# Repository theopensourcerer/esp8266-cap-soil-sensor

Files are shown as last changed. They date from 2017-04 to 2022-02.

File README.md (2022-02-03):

# ESP8266 Capacitive Soil Moisture Sensor
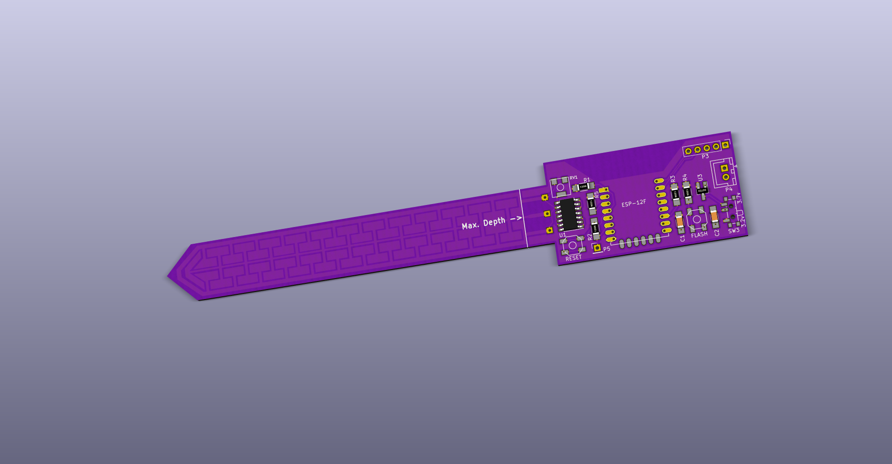
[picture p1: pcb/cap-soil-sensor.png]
Image of PCB

## Table of Contents
* [Summary](#summary)
* [Hardware](#hardware)
* [Case](#case)
* [Code](#code)
* [Licenses](#licenses)

## Summary
This is a personal project to build a Capacitive Soil Moisture Sensor for my hobby of growing chillies.

The project consists of three parts: the hardware (PCB and Sensor(s) etc.(, the case to hold the sensor, and the software.

I wanted to design and build my own sensors with built in WiFi so they could operate "standalone" in my tunnel. I wanted them to run from a decent capacity battery such as an 18650 Li-ion and to be able to report back information at timely intervals to my home server and database. Ultimately I want to use this information to be able to automate the watering of my plants.

The Internet is a wonderful thing. I have spent many dark and long evenings through the 2016/17 winter, learning, reading and searching for information on Capacitive moisture sensors. There are numerous resources (and individual people behind each of them) I would like to thank for taking the time to design, document and discuss the various mechanisms for capacitive moisture measurement. Hopefully my own small contributions may help others in the future.

Why use capacitive sensors? 

* The cheap and traditional moisture sensor uses a resistive technique. That is, to put it simply, the probe usually consists of two electrically conductive "prongs" which are inserted into the soil with a known gap between them. As the moisture increases, the electrical resistance decreases. This technique works but is not ideal mostly due to electrolysis [1]. Essentially the probes deteriorate rapidly due to this phenomenom and hence the measurements also change and the probes need to be replaced quite frequently

* The resitive appraoch requires significantly more power (electric current) to operate than the capacitive technique, so battery life would be constrained

* The fundamental principle of the capacitive sensor is that you measure the time it takes for your capacitor (the probe) to charge. This charging period changes proportionately to the moisture level of the soil. It means there is no direct electrical contact between the soil and the probe (it is insulated) therefore should last a great deal longer

* It is harder to do; hence far more interesting to design and produce ;-)

Below is my list, in no particular order, of the online resources I found to be most helpful during my research (there were and are others; Google is your friend):

http://pcb.daince.net/doku.php?id=sensor_soil_2
http://zerocharactersleft.blogspot.co.uk/2011/11/pcb-as-capacitive-soil-moisture-sensor.html

https://www.dfrobot.com/wiki/index.php/Capacitive_Soil_Moisture_Sensor_SKU:SEN0193 (Bought one of these to test. It works)
https://github.com/Miceuz/i2c-moisture-sensor
and
https://wemakethings.net/chirp/ (Bought one of these - this works too)

http://www.instructables.com/id/Comparison-of-Capacitive-Soil-Probes/
and then
https://github.com/acolomitchi/cap-soil-moisture-v2 (I have used this probe design. Thanks acolomitchi)

Then I came across these few resources (thank you Google Translate)
* https://www.mikrocontroller.net/topic/335407

Which led me here:
* http://shop.thomasheldt.de/product_info.php?info=p90_giess-o-mat-sensor-kit.html (Bought a couple of these and they work)

Which then led me to:
* https://github.com/Zentris/erdfeuchtemessung

and
* https://github.com/lh84/moisture_sensor_esp12

I have also been following along with this project:
* https://luckyresistor.me/2017/02/08/how-to-design-a-cheap-plant-watering-sensor-part-1/
I really like the way this project has been analysed, designed and documented - much more so than mine which is a "try-something-and-see-if-it-works" approach.

These resources above gave me confidence that a custom design was possible so I set to work basing the Schematic and PCB on the work of the people above. The use of a Schmitt Trigger Inverter to "square" up the oscillations of the sensor probe means it can be read by pretty much any GPIO as long as the MCU is fast enough. The ESP8266 has some limitations in this regard so I considered using a half-wave rectifier to convert this to a simple analogue voltage but the work of Zentris and Lars(lh84) convinced me that the ESP8266 was capable of reading the frequency directly if it can be kept below about 150Khz.

This is _all_ still very much a work in progress. I have built a prototype board and have had it running on my desk but the results leave me rather confused :-(

## Hardware
The Schematic and PCB are designed in KiCAD. A version of this board has been fabricated but it is not the final version. Probably the most interesting part is the layout of the probe footprint itself. This came from acolomitchi as mentioned above. (I have modified the layout somewhat so it is more suited to an integrated PCB - I also made it a little longer as my target was for quite large pots).

## Case
The case is designed in OpenSCAD and is suitable for printing on a 3D Printer. The basic idea is that the PCB slides into the case. The PCB has about 1.5mm of empty space down each side of the board which should be enough to slot in place. The probe end of the PCB fits through the slot in the bottom of the case. There should be enough height to support the power connector (not tested) and the other half of the case holds an 18650 battery in a plastic holder. The "lid" screws on and has protrusions which should prevent the probe PCB and the battery from moving about too much. I plan to use something like silicon bathrooom sealant around the probe slot to prevent any moisture ingressing into the case. Please feel free to use and improve - within the terms of the license of course.

## Code
The software for the ESP8266 is in this directory. It should be fairly simple C code. The config.h file contains user-defined parameters. The ESP8266 code works like this: On power up the ESP attempts to connect to the WiFi network. If successful it then attempts to read the frequency of the capacitive sensor probe. If the Sensor probe is read successfully the data is formatted as a JSON object and sent to the MQTT broker. The ESP8266 also sends information about its supply voltage and the time it took to run this code loop. Finally the code puts the ESP into "Deep Sleep" for a preconfigured period.

## Licenses
* The software is GPL (http://www.gnu.org/licenses/) 
* The OpenSCAD case design, and the Schematic and PCB are Creative Commons Attribution-NonCommercial-ShareAlike 4.0 International Public License (https://creativecommons.org/licenses/by-nc-sa/4.0/)

[1] https://en.wikipedia.org/wiki/Electrolysis

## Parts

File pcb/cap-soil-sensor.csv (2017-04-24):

Reference | Value | Footprint | Datasheet | BOM
C1 | 10uF | Capacitors_SMD:C_1206_HandSoldering
C2 | 1uF | Capacitors_SMD:C_1206_HandSoldering
R2 | 100 | Resistors_SMD:R_1206_HandSoldering
U2 | ESP-12F | ESP8266:ESP-12E
U3 | MCP1700T | TO_SOT_Packages_SMD:SOT-23_Handsoldering |  | IC MICROCHIP MCP1700T-vv02E/TT
P4 | PWR | Connectors_JST:JST_XH_B02B-XH-A_02x2.50mm_Straight
P3 | SERIAL | Pin_Headers:Pin_Header_Straight_1x05_Pitch2.54mm
R1 | 10k | Resistors_SMD:R_1206_HandSoldering
R3 | 10k | Resistors_SMD:R_1206_HandSoldering
R4 | 10k | Resistors_SMD:R_1206_HandSoldering
R5 | 10k | Resistors_SMD:R_1206_HandSoldering
RV1 | POT-BOURNS-3364W | manuf:BOURNS-3364-W
SW3 | Switch_SPDT_x2 | switches:SW_SPDT_PCM12
P5 | INSPECTION | Pin_Headers:Pin_Header_Straight_1x01_Pitch2.54mm
CS1 | CS | cap-sensor:cap_sensor_probe
SW1 | RESET | switches:SKQGAFE010_Switch
SW2 | FLASH | switches:SKQGAFE010_Switch
U1 | 74LS14 | KiCad/Housings_SOIC.pretty:SOIC-14_3.9x8.7mm_Pitch1.27mm

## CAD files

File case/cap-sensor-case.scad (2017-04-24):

/**
 * Case for Capacitive Soil Sensors
 * 
 * License: Creative Commons Attribution-ShareAlike 4.0 International
 * Copyright 2017 Alan Lord
**/
$fn = 50;

l = 80;
w = 35;
h = 43;

prbw = 17;
prbd = 2;

wall = 2;

nutSize = 6;
nutHeight = 3;
nutThread = 3.2;
boltLength = 8;
fix=8;

pcbw = 29.5;
pcbh = 52.5;
pcbpad = 6.5;

pcbwctrs = 20.320;
pcbdctrs = 51.435;

sloth=((w-pcbw)/2)+1.5;

slotDepthFromTop = 15;

// Display the box
box();

// Display the lid
%lid();

module box() {
    %difference() { // The % makes the external wall transparent ot invisibble
        roundedCube(h+wall*2,w+wall*2,l+wall,nutThread);
        translate([wall,wall,wall]) {
            roundedCube(h,w,l,nutThread);
        }
        translate([slotDepthFromTop,((w+wall*2)-prbw)/2,0]) {
            cube([prbd,prbw,wall*2]);
        }
    }
    translate([slotDepthFromTop-wall,wall,wall]) {
        pcbSlot(pcbh);
    }
    translate([slotDepthFromTop-wall,w+wall-sloth,wall]) {
        pcbSlot(pcbh);
    }
    translate([slotDepthFromTop+wall*3,wall,wall]) {
        cube([1,w,l-wall*2]);
    }
    fixing();
    translate([0,(w+wall*2)-fix,0]) {
        fixing();
    }
    translate([(h+wall*2)-fix,(w+wall*2)-fix,0]) {
        fixing();
    }
    translate([(h+wall*2)-fix,0,0]) {
        fixing();
    }
    
    x=(h-22+wall);
    y=((w+wall*2)-21)/2;
    translate([x,y,wall]) {
        battery();
    }
}


module lid() {
    xtrns = nutHeight+wall+8.5;
    difference(){
        translate([0,0,l+wall]) {
            roundedCube(h+wall*2,w+wall*2,wall,nutThread);
        }
        translate([fix/2,fix/2,l+wall]) {
            cylinder(d=nutThread,h=wall);
        }
        translate([(h+wall*2)-fix/2,fix/2,l+wall]) {
            cylinder(d=nutThread,h=wall);
        }
        translate([(h+wall*2)-fix/2,(w+wall*2)-fix/2,l+wall]) {
            cylinder(d=nutThread,h=wall);
        }
        translate([fix/2,(w+wall*2)-fix/2,l+wall]) {
            cylinder(d=nutThread,h=wall);
        }
    }
    sloth=l-(pcbh+pcbpad)-1;
    translate([slotDepthFromTop-wall,((w+wall*2)-w)/2,l-sloth+wall]) {
        difference() {
            cube([wall*3,w,sloth]);
            translate([0,w/2,0]) {
                rotate([90,0,90]) cylinder(h=wall*3,d=5);
            }
        }
    }
    translate([h-10,(w+wall*2)/2,(l+wall)-3]) {
        cylinder(h=3,d=10);
    }

}

module bolt(width,height,thread,length,hull) {
    cylinder(d=width/(cos(180/6)), h=height, $fn=6);
    if(hull) {
        hull(){
            translate([0,0,height]) {
                cylinder(d=thread,h=length);
            }
            translate([thread,0,height]) {
                cylinder(d=thread,h=length);
            }
        }
    } else {
        translate([0,0,height]) {
            cylinder(d=thread,h=length);
        }
    }
}

module fixing() {
    difference() {
        translate([0,0,wall]){
            roundedCube(fix,fix,l,nutThread);
        }
        translate([fix/2,fix/2,l-(boltLength-wall)]) {
            cylinder(d=nutThread,h=boltLength);
        }
    }
}

module battery() {
    l=76;
    w=21;
    h=22;
    cube([h,w,l]);
}

module pcbSlot(l) {
    cube([wall,sloth,l+pcbpad]);
    translate([wall*2,0,0]) {
        cube([wall,sloth,l+pcbpad]);
    }
    translate([wall,0,0]) {
        cube([prbd,sloth,pcbpad]);
    }
}

module roundedCube(xdim,ydim,zdim,rdim) {
    hull() {
        translate([rdim,rdim,0]) cylinder(r=rdim,h=zdim);
        translate([xdim-rdim,rdim,0]) cylinder(r=rdim,h=zdim);
        translate([rdim,ydim-rdim,0]) cylinder(r=rdim,h=zdim);
        translate([xdim-rdim,ydim-rdim,0]) cylinder(r=rdim,h=zdim);
    }
}

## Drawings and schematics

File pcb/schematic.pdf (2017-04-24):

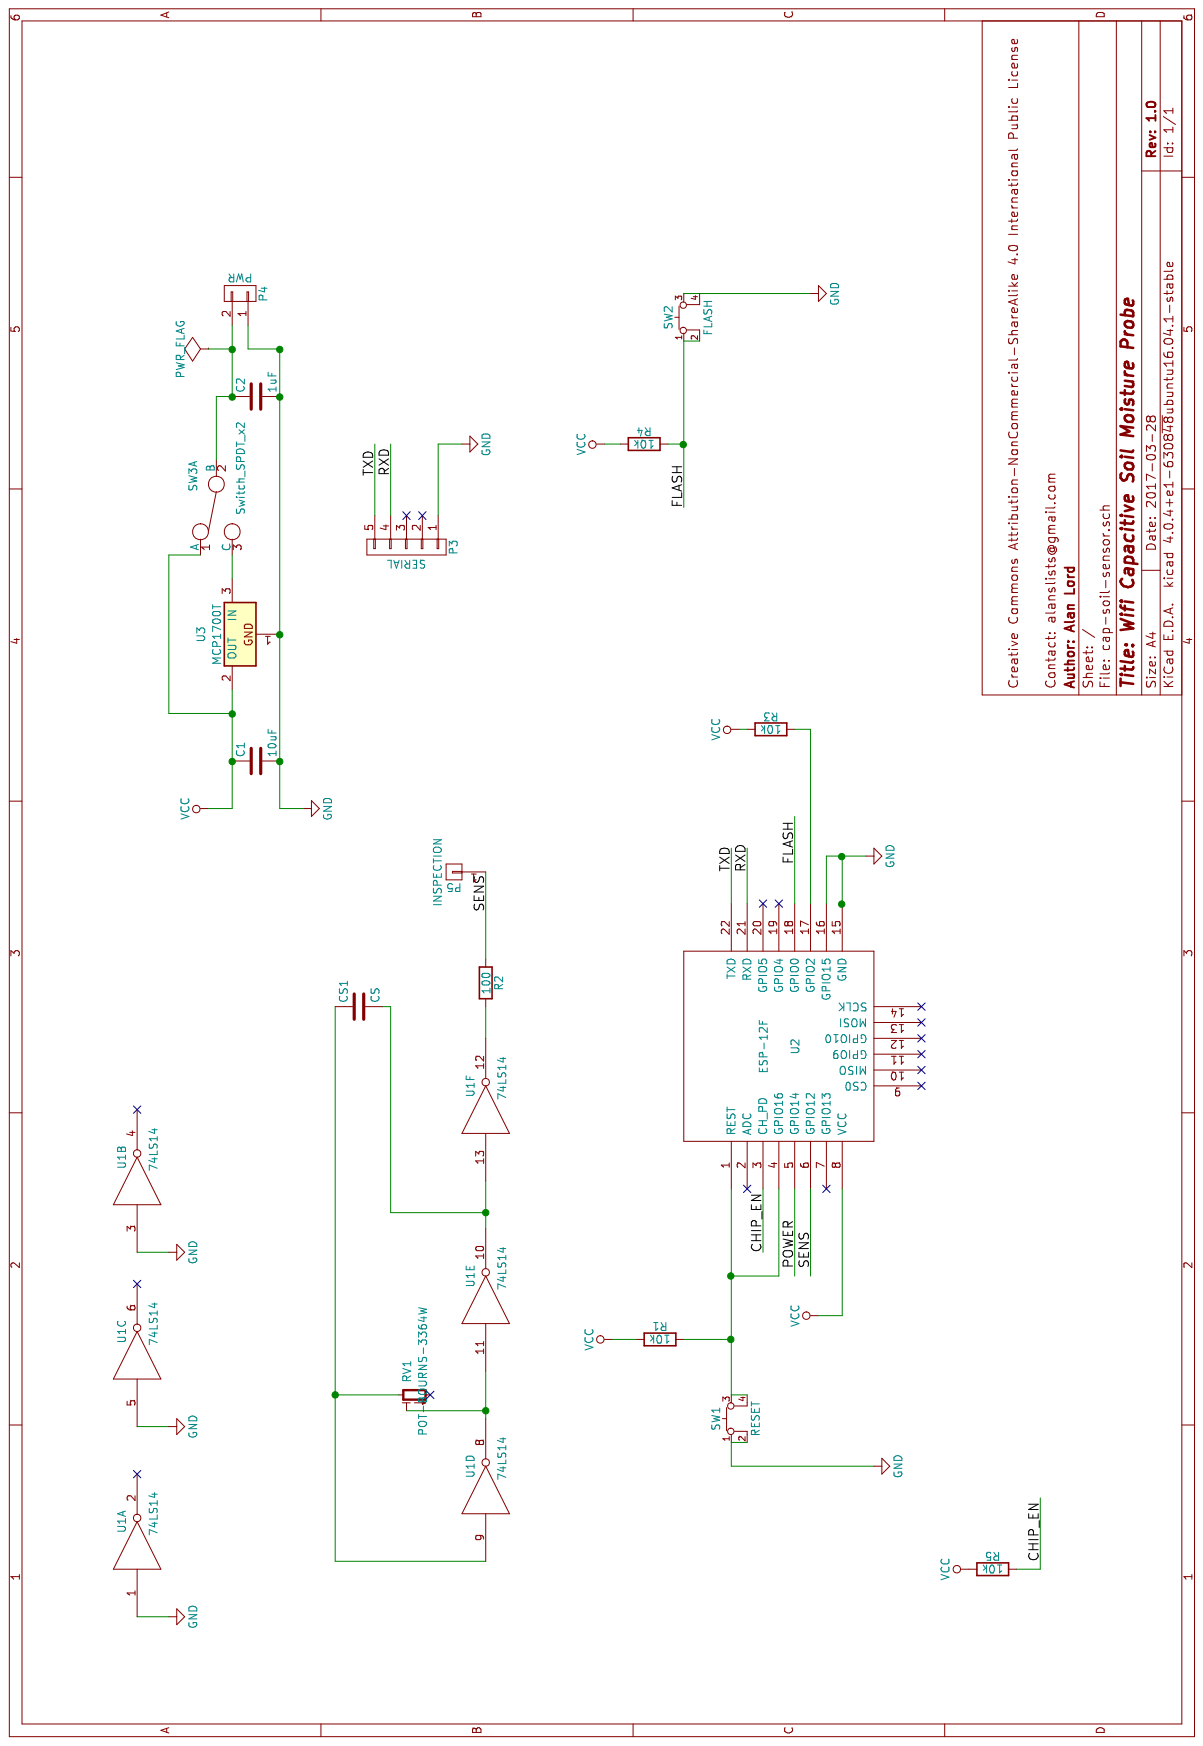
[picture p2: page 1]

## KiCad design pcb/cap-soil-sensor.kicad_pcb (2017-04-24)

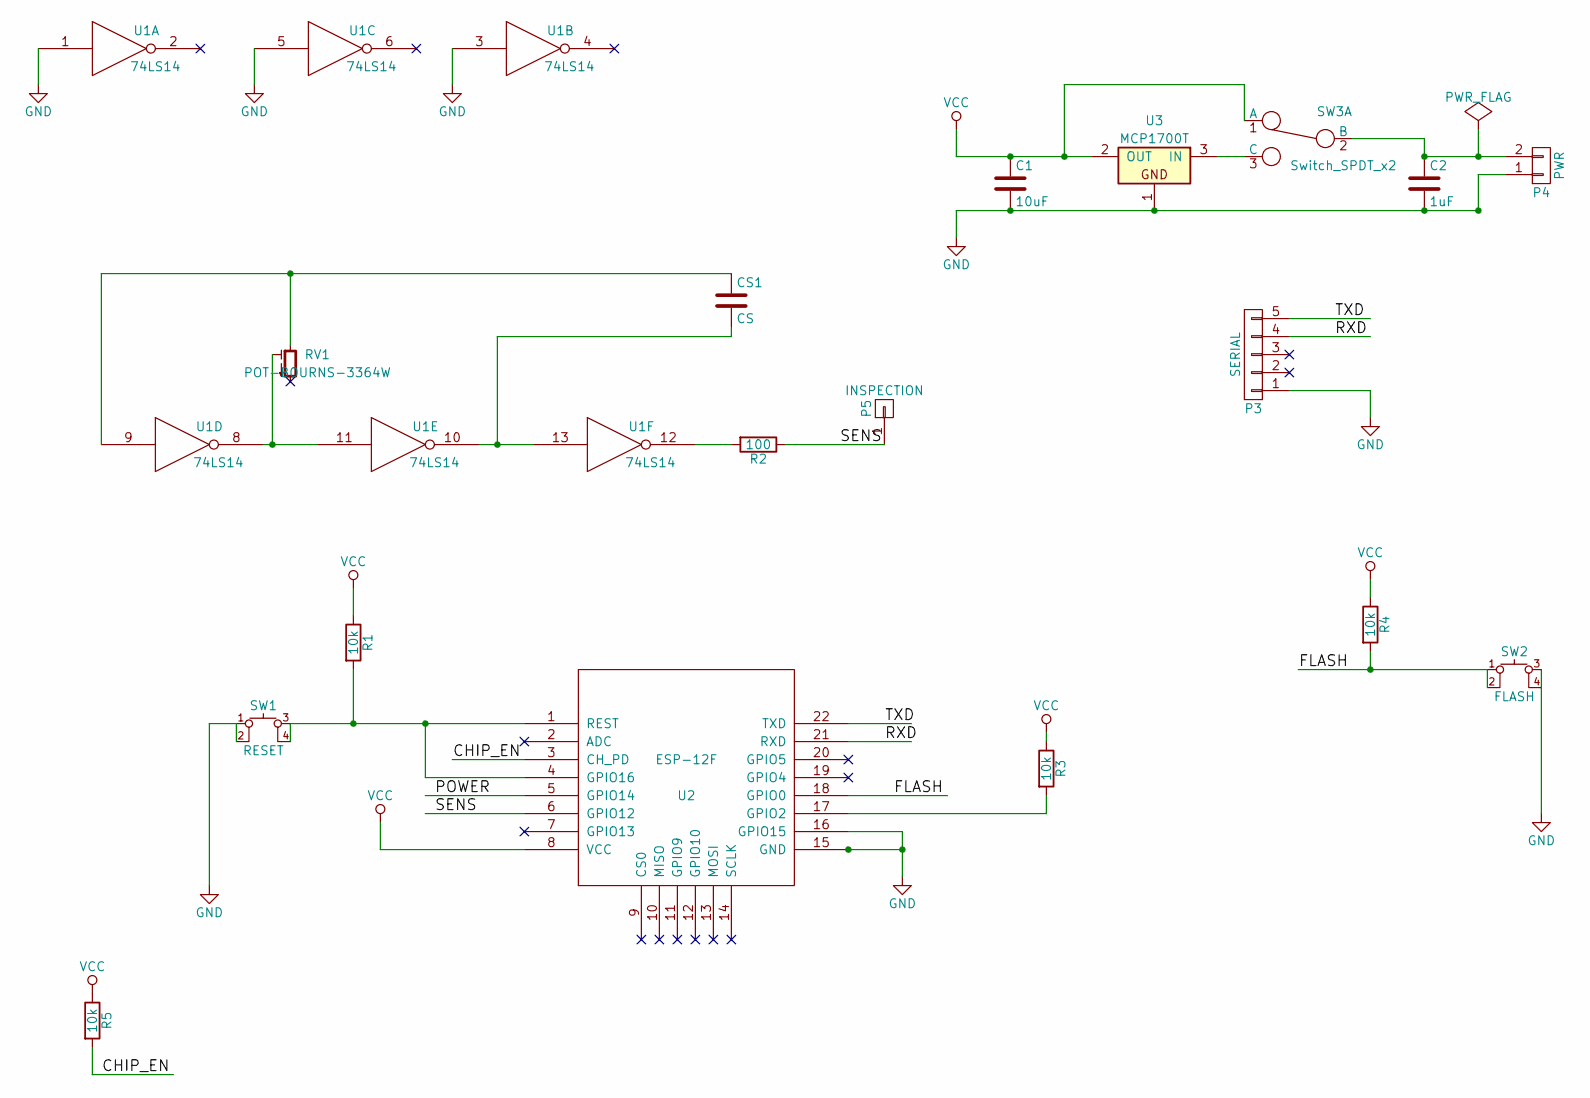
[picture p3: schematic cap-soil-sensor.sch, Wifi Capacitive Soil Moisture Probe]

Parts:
C1: 10uF; C_1206_HandSoldering
C2: 1uF; C_1206_HandSoldering
CS1: CS; cap_sensor_probe
P3: SERIAL; Pin_Header_Straight_1x05_Pitch2.54mm
P4: PWR; JST_XH_B02B-XH-A_02x2.50mm_Straight
P5: INSPECTION; Pin_Header_Straight_1x01_Pitch2.54mm
R1, R3, R4, R5: 10k; R_1206_HandSoldering
R2: 100; R_1206_HandSoldering
RV1: POT-BOURNS-3364W; BOURNS-3364-W
SW1: RESET; SKQGAFE010_Switch
SW2: FLASH; SKQGAFE010_Switch
SW3: Switch_SPDT_x2; SW_SPDT_PCM12
U1: 74LS14; SOIC-14_3.9x8.7mm_Pitch1.27mm
U2: ESP-12F; ESP-12E
U3: MCP1700T; SOT-23_Handsoldering

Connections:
/CHIP_EN: R5.2, U2.3 (CH_PD)
/FLASH: R4.2, SW2.1, SW2.2, U2.18 (GPIO0)
/RXD: P3.4, U2.21 (RXD)
/SENS: P5.1, R2.1, U2.6 (GPIO12)
/TXD: P3.5, U2.22 (TXD)
GND: C1.2, C2.2, P3.1, P4.1, SW1.1, SW1.2, SW2.3, U1.1, U1.3, U1.5, U1.7 (GND), U2.15 (GND), U2.16 (GPIO15), U3.1
unnamed: C2.1, P4.2, SW3.2 (B)
unnamed: CS1.1, RV1.3, U1.9
unnamed: CS1.2, U1.10, U1.13
unnamed: R1.2, SW1.3, SW1.4, U2.1 (REST), U2.4 (GPIO16)
unnamed: R2.2, U1.12
unnamed: R3.2, U2.17 (GPIO2)
unnamed: RV1.2, U1.8, U1.11
unnamed: SW3.3 (C), U3.3 (IN)
POWER: U1.14 (POWER), U2.5 (GPIO14)
VCC: C1.1, R1.1, R3.1, R4.1, R5.1, SW3.1 (A), U2.8 (VCC), U3.2 (OUT)

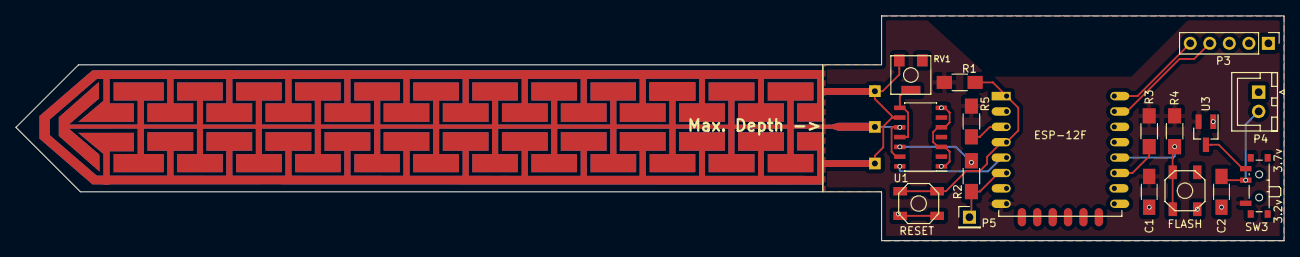
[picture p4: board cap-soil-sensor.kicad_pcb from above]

Board: 2 copper layers, 164.8 x 29.2 mm, 18 parts (0 on the bottom side), 16 nets.

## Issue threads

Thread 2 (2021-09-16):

ISR not in IRAM!

ChipStewart1, 2021-09-16:
I hope I'm not breaking protocol here, but I'm a bit of a noob.  After looking at some different projects, I thought this one looked like what I wanted, so I  had 20 boards printed up at JLC PCB and am trying to get them up and running.  I wasn't able to do it in PlatformIO, mostly because I couldn't get PubSubClient to work.  So I brought it over to Arduino IDE.  I got it to load (although I had to roll JSON back), but when I restart it, I get the following on the Serial Monitor:

...........
WiFi connected
IP address:
192.168.1.187
Attempting MQTT connection...Connected
ISR not in IRAM!

User exception (panic/abort/assert)
--------------- CUT HERE FOR EXCEPTION DECODER ---------------

Abort called

>>>stack>>>

ctx: cont
sp: 3ffffeb0 end: 3fffffc0 offset: 0000
3ffffeb0:  00000002 3ffffee2 3ffee748 4020350c
3ffffec0:  000000fe 00000000 00000000 00000000
3ffffed0:  00000000 00000000 00000000 00ff0000
3ffffee0:  5ffffe00 5ffffe00 401002a1 00000000
3ffffef0:  00000000 00000001 0000000c 4020512e
3fffff00:  401005a5 3ffee748 00000000 40205140
3fffff10:  00000000 00000002 0000000c 40205649
3fffff20:  3ffe8978 4b045454 c45a1c01 3ffee96c
3fffff30:  3fffff74 3ffee7b8 3fffff50 402056e8
3fffff40:  40203cf8 3ffe8976 3ffee82c 402012d4
3fffff50:  40203cf8 3ffe8976 3ffee82c 40203f64
3fffff60:  3fffdad0 00000009 3ffee82c 40204048
3fffff70:  00000000 3ffee748 3ffee82c 4020779d
3fffff80:  40207d50 3ffee748 3ffee82c 3ffee96c
3fffff90:  3fffdad0 00000000 3ffee958 40202255
3fffffa0:  feefeffe feefeffe feefeffe 40204c74
3fffffb0:  feefeffe feefeffe 3ffe863c 40100e61
<<<stack<<<

--------------- CUT HERE FOR EXCEPTION DECODER ---------------

 ets Jan  8 2013,rst cause:2, boot mode:(3,7)

load 0x4010f000, len 3460, room 16
tail 4
chksum 0xcc
load 0x3fff20b8, len 40, room 4
tail 4
chksum 0xc9
csum 0xc9
v00046480
~ld

...............................................

Any ideas how to solve this?  I'd like to start using these things!
Thanks,
Chip

theopensourcerer, 2021-09-17:
Gosh - I'm really sorry but I have not touched this project for about 5 years now. It really was, as I stated in the [Readme](https://github.com/theopensourcerer/esp8266-cap-soil-sensor/blob/master/README.md):

> "This is all still very much a work in progress. I have built a prototype board and have had it running on my desk but the results leave me rather confused :-("

As I recall there were some bugs in the PCB layout design too; it really was very much a prototype. i.e. things like the variable resistor should be replaced by a fixed one and most of the test points removed etc...

Having said all that it did "work" to a fashion on my desk in a pot but I never got any further than that, sorry.

ChipStewart1, 2021-09-22:
Thanks for your quick reply.  Looks like the only problem I can see now is due to the changes from json 5 to 6.  Unfortunately, I'm a beginner with PlatformIO and not familiar with json.  I think I was able to upgrade the first two json lines using the json upgrade guide, but can't figure out the others.  I'll post the errors below.  I'd greatly appreciate any help you could provide, and I'm sure others would benefit from a GitHub update.

BTW, I noticed you discussed PCB  water ingress and water proofing elsewhere online.  If you're interested, I'm comparing Liquid Tape, FlexSeal Clear, PlastiDip and perhaps silicone and/or urethane conformal coatings and can let you know the results.

Thanks
Chip

Oh, and let me know if you want me to send you some seeds from my Cajun Belle and Fish pepper plants.  The later is a very interesting African-American heirloom from the Philadelphia/Baltimore region with beautiful variegated leaves and fruit and Caribbean flavor and heat.

Errors:

src\main.cpp:140:11: error: StaticJsonBuffer is a class from ArduinoJson 5. Please see https://arduinojson.org/upgrade to learn how to upgrade your program to ArduinoJson version 6
.pio\libdeps\esp12e\PubSubClient\src\PubSubClient.cpp: In member function 'boolean PubSubClient::publish_P(const char*, const uint8_t*, unsigned int, boolean)':
.pio\libdeps\esp12e\PubSubClient\src\PubSubClient.cpp:523:16: warning: comparison of integer
expressions of different signedness: 'unsigned int' and 'int' [-Wsign-compare]
  523 |     return (rc == expectedLength);
      |             ~~~^~~~~~~~~~~~~~~~~
Compiling .pio\build\esp12e\lib80f\ESP8266WiFi\ESP8266WiFiSTA.cpp.o
Compiling .pio\build\esp12e\lib80f\ESP8266WiFi\ESP8266WiFiScan.cpp.o
Compiling .pio\build\esp12e\lib80f\ESP8266WiFi\WiFiClient.cpp.o
Compiling .pio\build\esp12e\lib80f\ESP8266WiFi\WiFiClientSecureBearSSL.cpp.o
src\main.cpp: In function 'void setup_wifi()':
src\main.cpp:82:31: warning: comparison of integer expressions of different signedness: 'long unsigned int' and 'long int' [-Wsign-compare]
   82 |     if (millis() - startMills > WIFI_TIMEOUT) {
      |         ~~~~~~~~~~~~~~~~~~~~~~^~~~~~~~~~~~~~
src\main.cpp: In function 'void publishJSON()':
src\main.cpp:140:21: error: expected primary-expression before '<' token
  140 |     StaticJsonBuffer<150> jsonBuffer;
      |                     ^
src\main.cpp:140:27: error: 'jsonBuffer' was not declared in this scope; did you mean 'JsonBuffer'?
  140 |     StaticJsonBuffer<150> jsonBuffer;
      |                           ^~~~~~~~~~
      |                           JsonBuffer
src\main.cpp:142:48: error: cannot bind non-const lvalue reference of type 'ArduinoJson::JsonArray&' {aka 'ArduinoJson6184_91::ArrayRef&'} to an rvalue of type 'ArduinoJson6184_91::ArrayRef'
  142 |     JsonArray& payload = root.createNestedArray("payload");
      |                          ~~~~~~~~~~~~~~~~~~~~~~^~~~~~~~~~~
src\main.cpp:143:50: error: cannot bind non-const lvalue reference of type 'ArduinoJson::JsonObject&' {aka 'ArduinoJson6184_91::ObjectRef&'} to an rvalue of type 'ArduinoJson6184_91::ObjectRef'
  143 |     JsonObject& data = payload.createNestedObject();
      |                        ~~~~~~~~~~~~~~~~~~~~~~~~~~^~
src\main.cpp:150:12: error: 'ArduinoJson::JsonObject' {aka 'class ArduinoJson6184_91::ObjectRef'} has no member named 'prettyPrintTo'
  150 |       root.prettyPrintTo(Serial);
      |            ^~~~~~~~~~~~~
src\main.cpp:154:10: error: 'ArduinoJson::JsonObject' {aka 'class ArduinoJson6184_91::ObjectRef'} has no member named 'printTo'
  154 |     root.printTo(buffer, sizeof(buffer));
      |          ^~~~~~~
src\main.cpp:155:5: warning: this 'if' clause does not guard... [-Wmisleading-indentation]
  155 |     if (client.publish(TOPIC, buffer));
      |     ^~
src\main.cpp:156:7: note: ...this statement, but the latter is misleadingly indented as if it were guarded by the 'if'
  156 |       if (DEBUG_PRINT) {
      |       ^~
*** [.pio\build\esp12e\src\main.cpp.o] Error 1

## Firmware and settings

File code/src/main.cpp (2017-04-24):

/*
                 GNU GENERAL PUBLIC LICENSE
                  Version 3, 29 June 2007
  This program is free software: you can redistribute it and/or modify
  it under the terms of the GNU General Public License as published by
  the Free Software Foundation, either version 3 of the License, or
  (at your option) any later version.
  This program is distributed in the hope that it will be useful,
  but WITHOUT ANY WARRANTY; without even the implied warranty of
  MERCHANTABILITY or FITNESS FOR A PARTICULAR PURPOSE.  See the
  GNU General Public License for more details.
  You should have received a copy of the GNU General Public License
  along with this program.  If not, see <http://www.gnu.org/licenses/>.
 - - - - - - - - - - - - - - - - - - - - - - - - - - - - - - - - - - - -

 Original code sources from:
  Erdfeuchtemessung mit ESP8266-01 / ESP8266-12(e)
  Measure soil moisture with ESP8266-01 / ESP8266-12(e)
  (2016)
  @Autors:
    - Ralf Wießner (aka Zentris)
  https://github.com/Zentris/erdfeuchtemessung
*/
#include "config.h"

#include <ESP8266WiFi.h>
#include <PubSubClient.h>
#include <ArduinoJson.h>

// Expose Espressif SDK functionality
extern "C" {
    #include "user_interface.h"
}

// Set up ESP8266 ADC for voltage read
ADC_MODE(ADC_VCC);
float vcc;

// Sensor average
unsigned long soilMoistAveraged;

volatile unsigned long counter = 0; // interrupt loop counter

// Timer placeholders
unsigned long startMills = 0;

// Function Prototypes
void readSensor();
void setup_wifi();
void reconnect();
void publishJSON();
void goingToSleep();
// End Prototypes

// Begin code
WiFiClient espClient;
PubSubClient client(espClient);

void setup() {
  startMills = millis();
  vcc = ESP.getVcc();
  Serial.begin(115200);

  digitalWrite(POWER_PIN, HIGH);  // switch sensor power on

  setup_wifi();
  client.setServer(MQTT_SERVER, 1883);
}

void setup_wifi() {
  // We start by connecting to a WiFi network
  if (DEBUG_PRINT) {
    Serial.println();
    Serial.print("Connecting to ");
    Serial.println(WIFI_SSID);
  }
  WiFi.begin(WIFI_SSID, WIFI_PASSWORD);

  while (WiFi.status() != WL_CONNECTED) {
    delay(500);
    Serial.print(".");
    if (millis() - startMills > WIFI_TIMEOUT) {
      if (DEBUG_PRINT) {
        Serial.println("Taken too long to connect to WiFi. Going to sleep");
      }
      goingToSleep();
    }
  }

  if (DEBUG_PRINT) {
    Serial.println("");
    Serial.println("WiFi connected");
    Serial.println("IP address: ");
    Serial.println(WiFi.localIP());
  }
}

void loop() {
  if (!client.connected()) {
    reconnect();
  }

  readSensor();

  if(soilMoistAveraged) {
    if (DEBUG_PRINT) {
      Serial.print("Read Sensor. Publish message: ");
    }
    publishJSON();
  }

  goingToSleep();
}

void reconnect() {
  // Loop until we're reconnected
  while (!client.connected()) {
    if (DEBUG_PRINT) {
      Serial.print("Attempting MQTT connection...");
    }
    // Attempt to connect
    if (client.connect("CapSensor")) {
      if (DEBUG_PRINT) {
        Serial.println("Connected");
      }
    } else {
      if (DEBUG_PRINT) {
        Serial.print("Failed to connect. State = ");
        Serial.print(client.state());
        Serial.println(" Retry in 2 seconds");
      }
      // Wait 2 seconds before retrying
      delay(2000);
    }
  }
}

void publishJSON() {
  if (client.connected()) {
    StaticJsonBuffer<150> jsonBuffer;
    JsonObject& root = jsonBuffer.createObject();
    JsonArray& payload = root.createNestedArray("payload");
    JsonObject& data = payload.createNestedObject();
    data["sensorid"] = SENSORNAME;
    data["moisture"] = soilMoistAveraged;
    data["vcc"] = vcc/1000;
    data["cycletime"] = millis() - startMills;
    if (DEBUG_PRINT) {
      Serial.print("Sending payload: ");
      root.prettyPrintTo(Serial);
    }

    char buffer[150];
    root.printTo(buffer, sizeof(buffer));
    if (client.publish(TOPIC, buffer));
      if (DEBUG_PRINT) {
        Serial.print("Published OK  --> ");
        Serial.println(millis() - startMills);
      }
    } else {
      if (DEBUG_PRINT) {
        Serial.print("Publish failed --> ");
        Serial.println(millis() - startMills);
      }
    }
}

/**
 * Simple median/average calculation
 * ------------------------------------
 * Getting array will be sorted and now get the average over the middle values
 */
unsigned long median(unsigned long *values, size_t arraySize) {
  unsigned long tmp = 0;     // set to 0, make the compiler happy :-)
  const size_t relVal = 2;   // +- 2 Werte + 1 für die Mittelwertberechnung

  for (size_t i=0; i < arraySize-2; i++) {
    for (size_t j=arraySize-1; j > i; j--) {
      if ( values[j] < values[j-1] ) {
        tmp = values[j];
        values[j] = values[j-1];
        values[j-1] = tmp;
      }
    }
  }

  if (DEBUG_PRINT) {
    for (size_t x=0; x<arraySize; x++) {
      Serial.print("Values: ");
      Serial.print(values[x]);
    }
  }

  tmp = 0;
  for (size_t i=arraySize/2-relVal; i<arraySize/2+relVal+1; tmp +=values[i++]) {}
  return tmp/(relVal*2+1) * 1000/MEASURING_TIME;
}

/**
 * Interrupt function: increment the counter
 */
void intfunc() {
  counter++;
}

void readSensor() {
  unsigned long dataArray[MEASURING_INTERVALS];

  for (size_t i=0; i < MEASURING_INTERVALS; i++) {
    //Serial << F("[bodenfeuchtemessung] SensorID: ") << sensordata.sensorId << F(" - Measuring No.: ") << i << F(" on GPIO-Pin ") << sensordata.intGPIO << F(" = ");
    counter = 0;

    attachInterrupt(SENSOR_PIN, intfunc, RISING);
    delay(MEASURING_TIME);
    detachInterrupt(SENSOR_PIN);
    dataArray[i] = counter;
    delay(100);         // wait a small time
  }

  digitalWrite(POWER_PIN, LOW);   // switch sensor power off

  soilMoistAveraged = median(dataArray, MEASURING_INTERVALS);

  if (DEBUG_PRINT) {
    Serial.print("Sensor Average: ");
    Serial.print(soilMoistAveraged);
  }
}

void goingToSleep() {
  // All Good
  if (DEBUG_PRINT) {
    Serial.print("About to go to sleep: Time taken to complete cycle: ");
    Serial.println(millis() - startMills);
  }
  client.disconnect();
  yield();
  WiFi.disconnect();
  WiFi.mode(WIFI_OFF);
  WiFi.forceSleepBegin();
  ESP.deepSleep(deep_sleep, DS_MODE);
  //ESP.deepSleep(0);
  delay(250);
}

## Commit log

2017-04-24 Clean up and update static files
    [cap-soil-sensor-Edge.Cuts.gm1]
2022-02-03 Update README.md
    Add image of PCB
